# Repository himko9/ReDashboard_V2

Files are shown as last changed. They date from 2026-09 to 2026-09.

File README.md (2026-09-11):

# N-in-One Enhanced ReDashboard - Open-Source "EZ Dashboard" Based on the RP2040 MCU

English | [简体中文](./README.zh-CN.md)

<table>
  <tr>
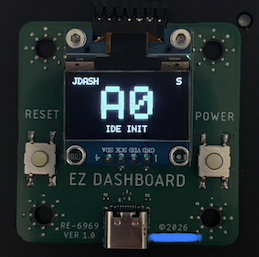
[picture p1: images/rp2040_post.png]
    <td></td>
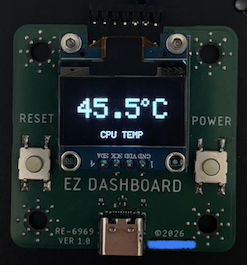
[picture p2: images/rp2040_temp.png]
    <td></td>
  </tr>
  <tr>
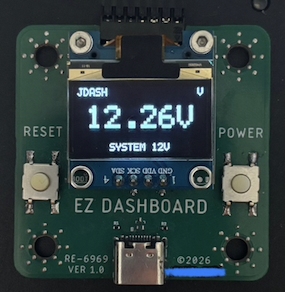
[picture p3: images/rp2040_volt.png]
    <td></td>
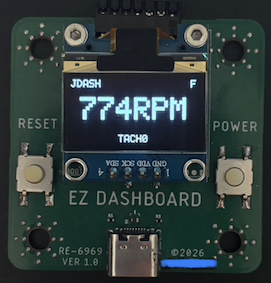
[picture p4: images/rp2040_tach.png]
    <td></td>
  </tr>
</table>

### Motherboard Support:

**Supports POST code monitoring through the following headers/interfaces:**

* JDASH1

* JDP1

* JBD1

* Any other UART header using 115200-8N1

**On MSI motherboards, connecting to "JDASH1" provides:**

* Display and logging of POST codes (Port80/81, 8-bit)

* Fan speed display

* System temperature display

* System voltage display

**On MSI motherboards, connecting to "JDP1" provides:**

* Display and logging of POST codes (Port80, 32-bit; Port81-83, 8-bit)

**On other motherboards, connecting to any header that outputs codes over UART 115200-8N1 provides:**

* Display and logging of POST codes (Port80, 8-bit)

**On all motherboards, additional connections to JBAT and JFP1 allow control of:**

* BIOS reset and system power on/off

### Firmware Features:

Code history:\
Supports caching P80 codes in the chip's internal memory.\
The onboard buttons can be used to scroll up and down through the recorded codes.

Code output:\
When connected via USB-C, the device operates as a USB CDC UART device.\
Supports decoded P80 code output.\
A future SDK will support voltage, temperature, and fan-speed logging.

Temperature / voltage / fan-speed sensors:\
Supports custom labels based on motherboard model.\
Supports Celsius / Fahrenheit temperature conversion.

OLED page control:\
Supports disabling unused pages, such as hiding the voltage page.\
Supports automatically returning to the home page after N seconds.\
Supports automatically waking the display when a significant change in temperature, voltage, or fan speed is detected.\
Supports automatically displaying updated POST codes.

OLED burn-in protection features:\
Pixel shifting.\
Automatic dimming.\
Automatic page-title hiding.\
Automatic display shutoff.

### Button Controls:

Short-press both side buttons -> Switch input source (JDASH/UART).\
Hold both side buttons for 3 seconds -> Switch button mode (page navigation mode / power-button mode).\
Hold both side buttons for 5 seconds -> Lock the JDASH/UART input and lock the buttons\
(buttons have no function while locked, Hold again to unlock).\
Hold both side buttons for 10 seconds -> Reset BIOS (NMOS connects JBAT1).

Press either side button 5 times consecutively -> Change page (switch display page).\
On the P80 page, hold either side button -> Scroll up/down through the P80 code history.

### BOM + Manufacturing Notes:
**If you want to reproduce the design directly, please note that the design was imported into JLCPCB/LCEDA from an external source.**\
**I cannot confirm whether Gerber files exported from this project can be used directly for PCB manufacturing.**\
**Please verify the schematic, PCB routing, and copper pours yourself.**\
**Using the Autodesk Eagle design files to generate gerber should be fine**

The reproduction cost is only about RMB 15:\
RMB 6 for a 0.96-inch, 4-pin I2C OLED module.\
RMB 5 for an RP2040 module, from which the RP2040, crystal oscillator, and SPI NOR flash are removed.\
RMB 4 for other capacitors, resistors, LDOs, and miscellaneous components.\
RMB 0 for a free 2-layer PCB (thanks to JLCPCB).

**Note:**\
Reproducing the RP2040 version of ReDashboard is not recommended here.\
A later version will use a PY32 as the main controller, reducing the chip cost significantly to about RMB 0.5, and requiring almost no external components.\
The firmware has already been written and successfully tested. It will be updated when I'm free.\
<br>

### Firmware and Firmware Source Code:
You can use the precompiled `firmware.uf2` file, but it is recommended that you modify the configuration and compile the firmware yourself.
<br>

### License:
Both the hardware and firmware of this project are licensed under the GPL (v3 or later).\
I provide no guarantees regarding the functionality or safety of this project.\
You are free to use, sell, and create products based on this project.

```
/*
 * This file is part of the "ReDashboard_V2" distribution.
 *
 * Copyright (C) 2026 @himko9 <me@himko.dev>
 * Github: https://github.com/himko9/ReDashboard_V2
 *
 * This program is free software: you can redistribute it and/or modify
 * it under the terms of the GNU General Public License as published by
 * the Free Software Foundation, either version 3 of the License, or
 * (at your option) any later version.
 *
 * This program is distributed in the hope that it will be useful,
 * but WITHOUT ANY WARRANTY; without even the implied warranty of
 * MERCHANTABILITY or FITNESS FOR A PARTICULAR PURPOSE.  See the
 * GNU General Public License for more details.
 *
 * You should have received a copy of the GNU General Public License
 * along with this program.  If not, see <https://www.gnu.org/licenses/>.
 */
 ```

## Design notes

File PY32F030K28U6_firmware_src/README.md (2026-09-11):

# EZ Dashboard PY32F030K28 Firmware

Standalone release source for the PY32F030K28U6 target. The required Puya
CMSIS/HAL files, startup code, and linker script are included.

## Requirements

- Arm GNU Toolchain with `arm-none-eabi-gcc` in `PATH`
- GNU Make for the Makefile build

## Build

On Windows:

```bat
build.bat
```

The Windows script only requires the Arm GNU Toolchain; GNU Make is not needed.

On Linux or macOS:

```sh
make
```

To use a toolchain outside `PATH`, set its executable prefix:

```sh
make PREFIX=/opt/arm-gnu-toolchain/bin/arm-none-eabi-
```

Build outputs are written to `build/`:

- `ez_dashboard_py32f030k28.elf`
- `ez_dashboard_py32f030k28.hex`
- `ez_dashboard_py32f030k28.bin`

The raw `.bin` image starts at flash address `0x08000000`. Use `make clean`
or `build.bat clean` to remove generated files.

Application and board settings are in the headers under `include/`.

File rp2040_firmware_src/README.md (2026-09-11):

# ReDashboard V2 - RP2040

This directory is a standalone Raspberry Pi Pico SDK project. It contains its
own firmware sources, configuration headers, POST-code table, PIO program,
Pico SDK import helper, and CMake project.

The user-editable configuration files are under `include/`:

- `app_config.h`: polling, display, button, sensor timing, and the percentage
  change required to wake the OLED.
- `display_config.h`: enabled pages, startup page, P81 decoding, and OLED
  power-saving/top-bar behavior.
- `sio_adc_config.h`: voltage/temperature channels, labels, and formulas.
- `sio_fan_config.h`: tachometer channels, labels, and formulas.
- `board_config.h`: RP2040 pins, buses, UARTs, buttons, and OLED rotation.

Configure and build from this directory with Pico SDK 2.2 or later:

```sh
cmake -S . -B build
cmake --build build --parallel
```

Targets:

- `redashboard`: normal P80-only flash build.
- `redashboard_p81_16bit`: P81/OUT16 flash build.
- `redashboard_ram`: normal P80-only RAM build.

By default, a valid sensor change greater than 10 percent wakes a dimmed or
powered-off OLED. The static source/role/lock top bar hides after 30 seconds
and reappears on activity. Configure these with
`SENSOR_WAKE_CHANGE_PERCENT` in `app_config.h` and
`DISPLAY_TOP_BAR_TIMEOUT_SECONDS` in `display_config.h`; zero disables the
corresponding feature.

UART mode keeps a lightweight P80-only JDASH probe active. A stable value is
used only as a baseline; a subsequent valid nonzero P80 transition switches
the display back to JDASH automatically. Configure its background interval
with `JDASH_DETECT_POLL_INTERVAL_MS` in `app_config.h`.

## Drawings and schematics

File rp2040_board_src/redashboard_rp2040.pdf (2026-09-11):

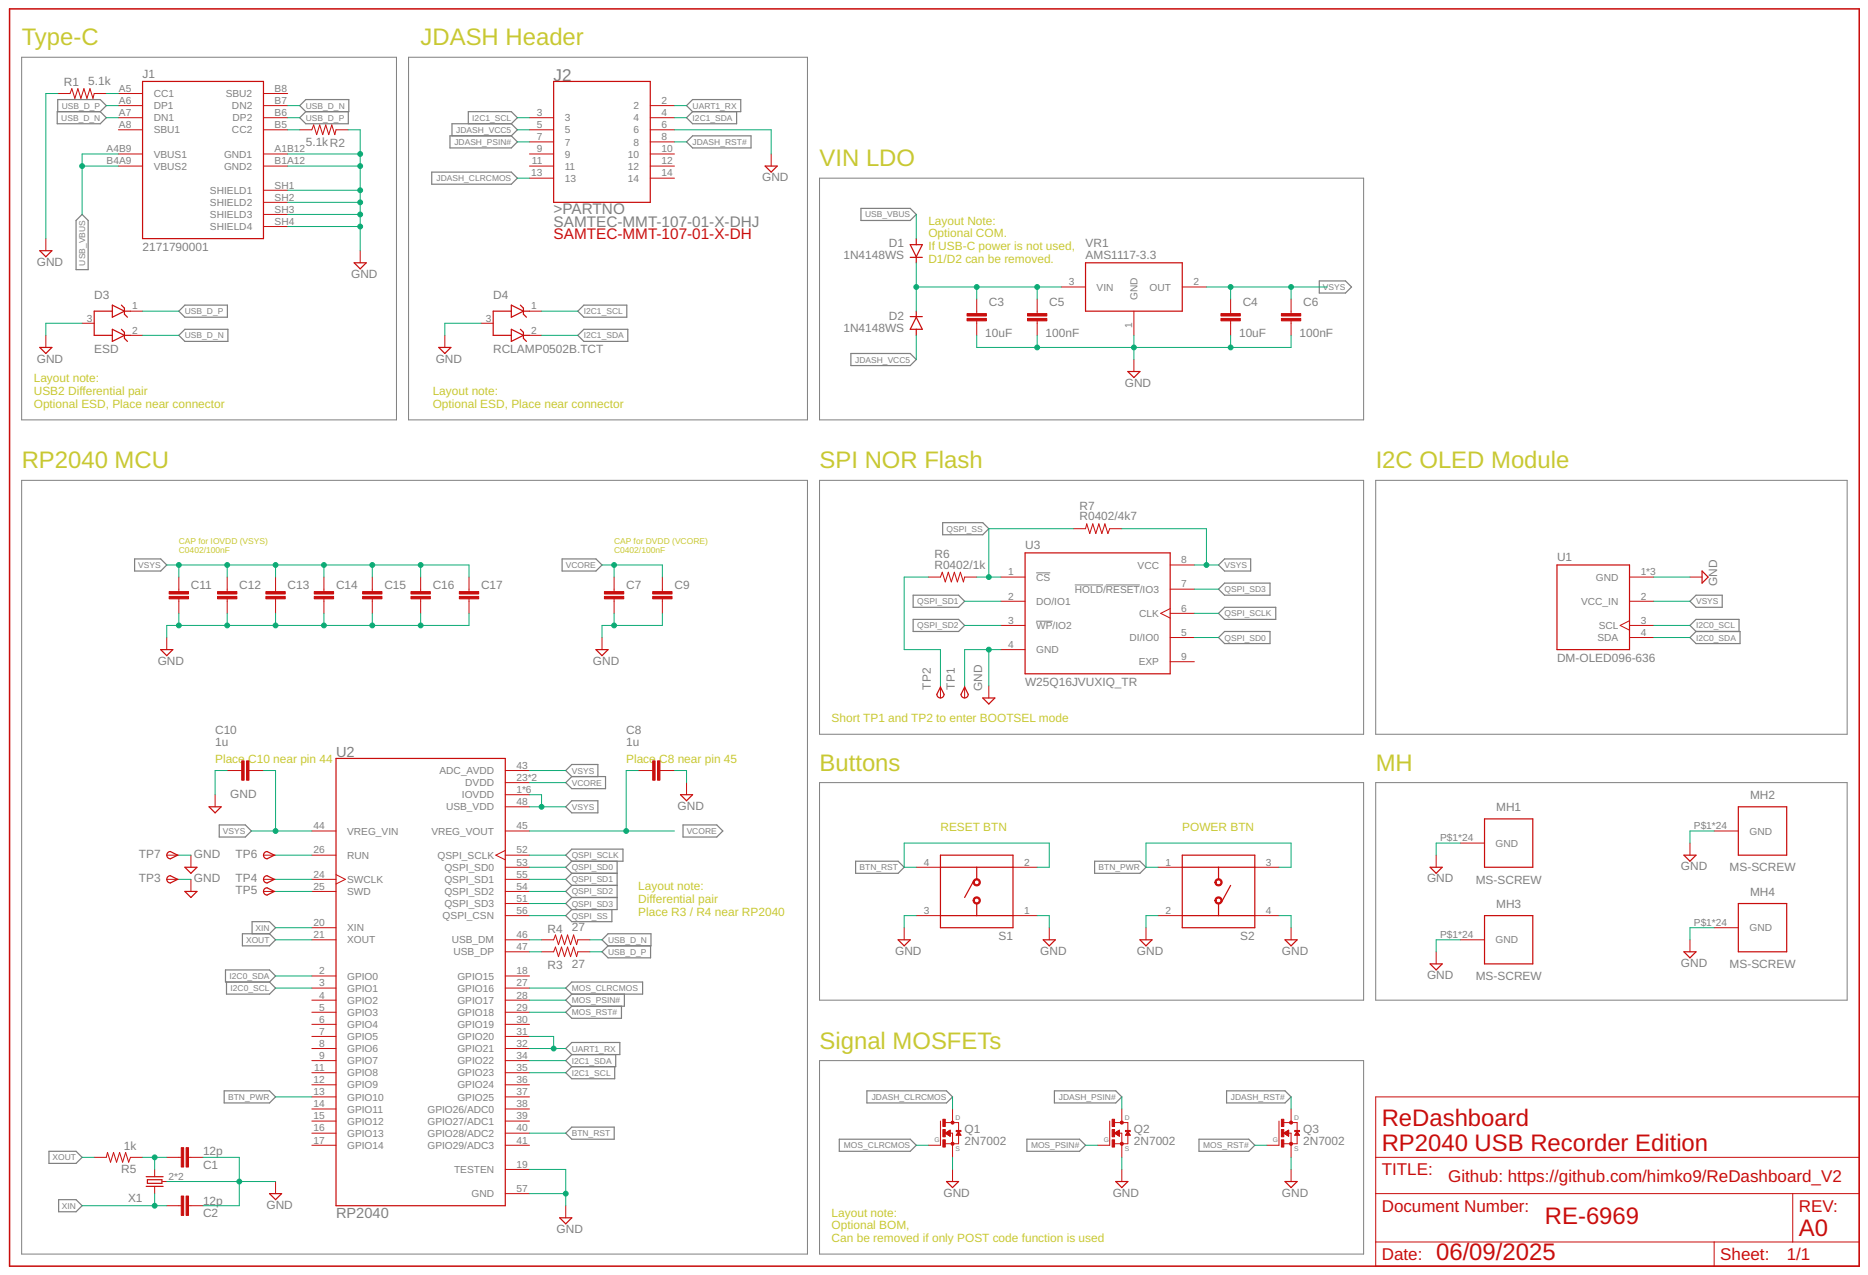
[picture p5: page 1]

Layout Note: Optional COM.

If USB-C power is not used, D1/D2 can be removed. RP2040 MCU
GND

Layout note: USB2 Differential pair Optional ESD, Place near connector

Layout note: Optional ESD, Place near connector

Short TP1 and TP2 to enter BOOTSEL mode
Buttons

Layout note: Differential pair Place R3 / R4 near RP2040

Github: https://github.com/himko9/ReDashboard_V2

Document Number: RE-6969 | REV: A0
06/09/2025 Date: | Sheet: 1/1

Layout note: Optional BOM, Can be removed if only POST code function is used

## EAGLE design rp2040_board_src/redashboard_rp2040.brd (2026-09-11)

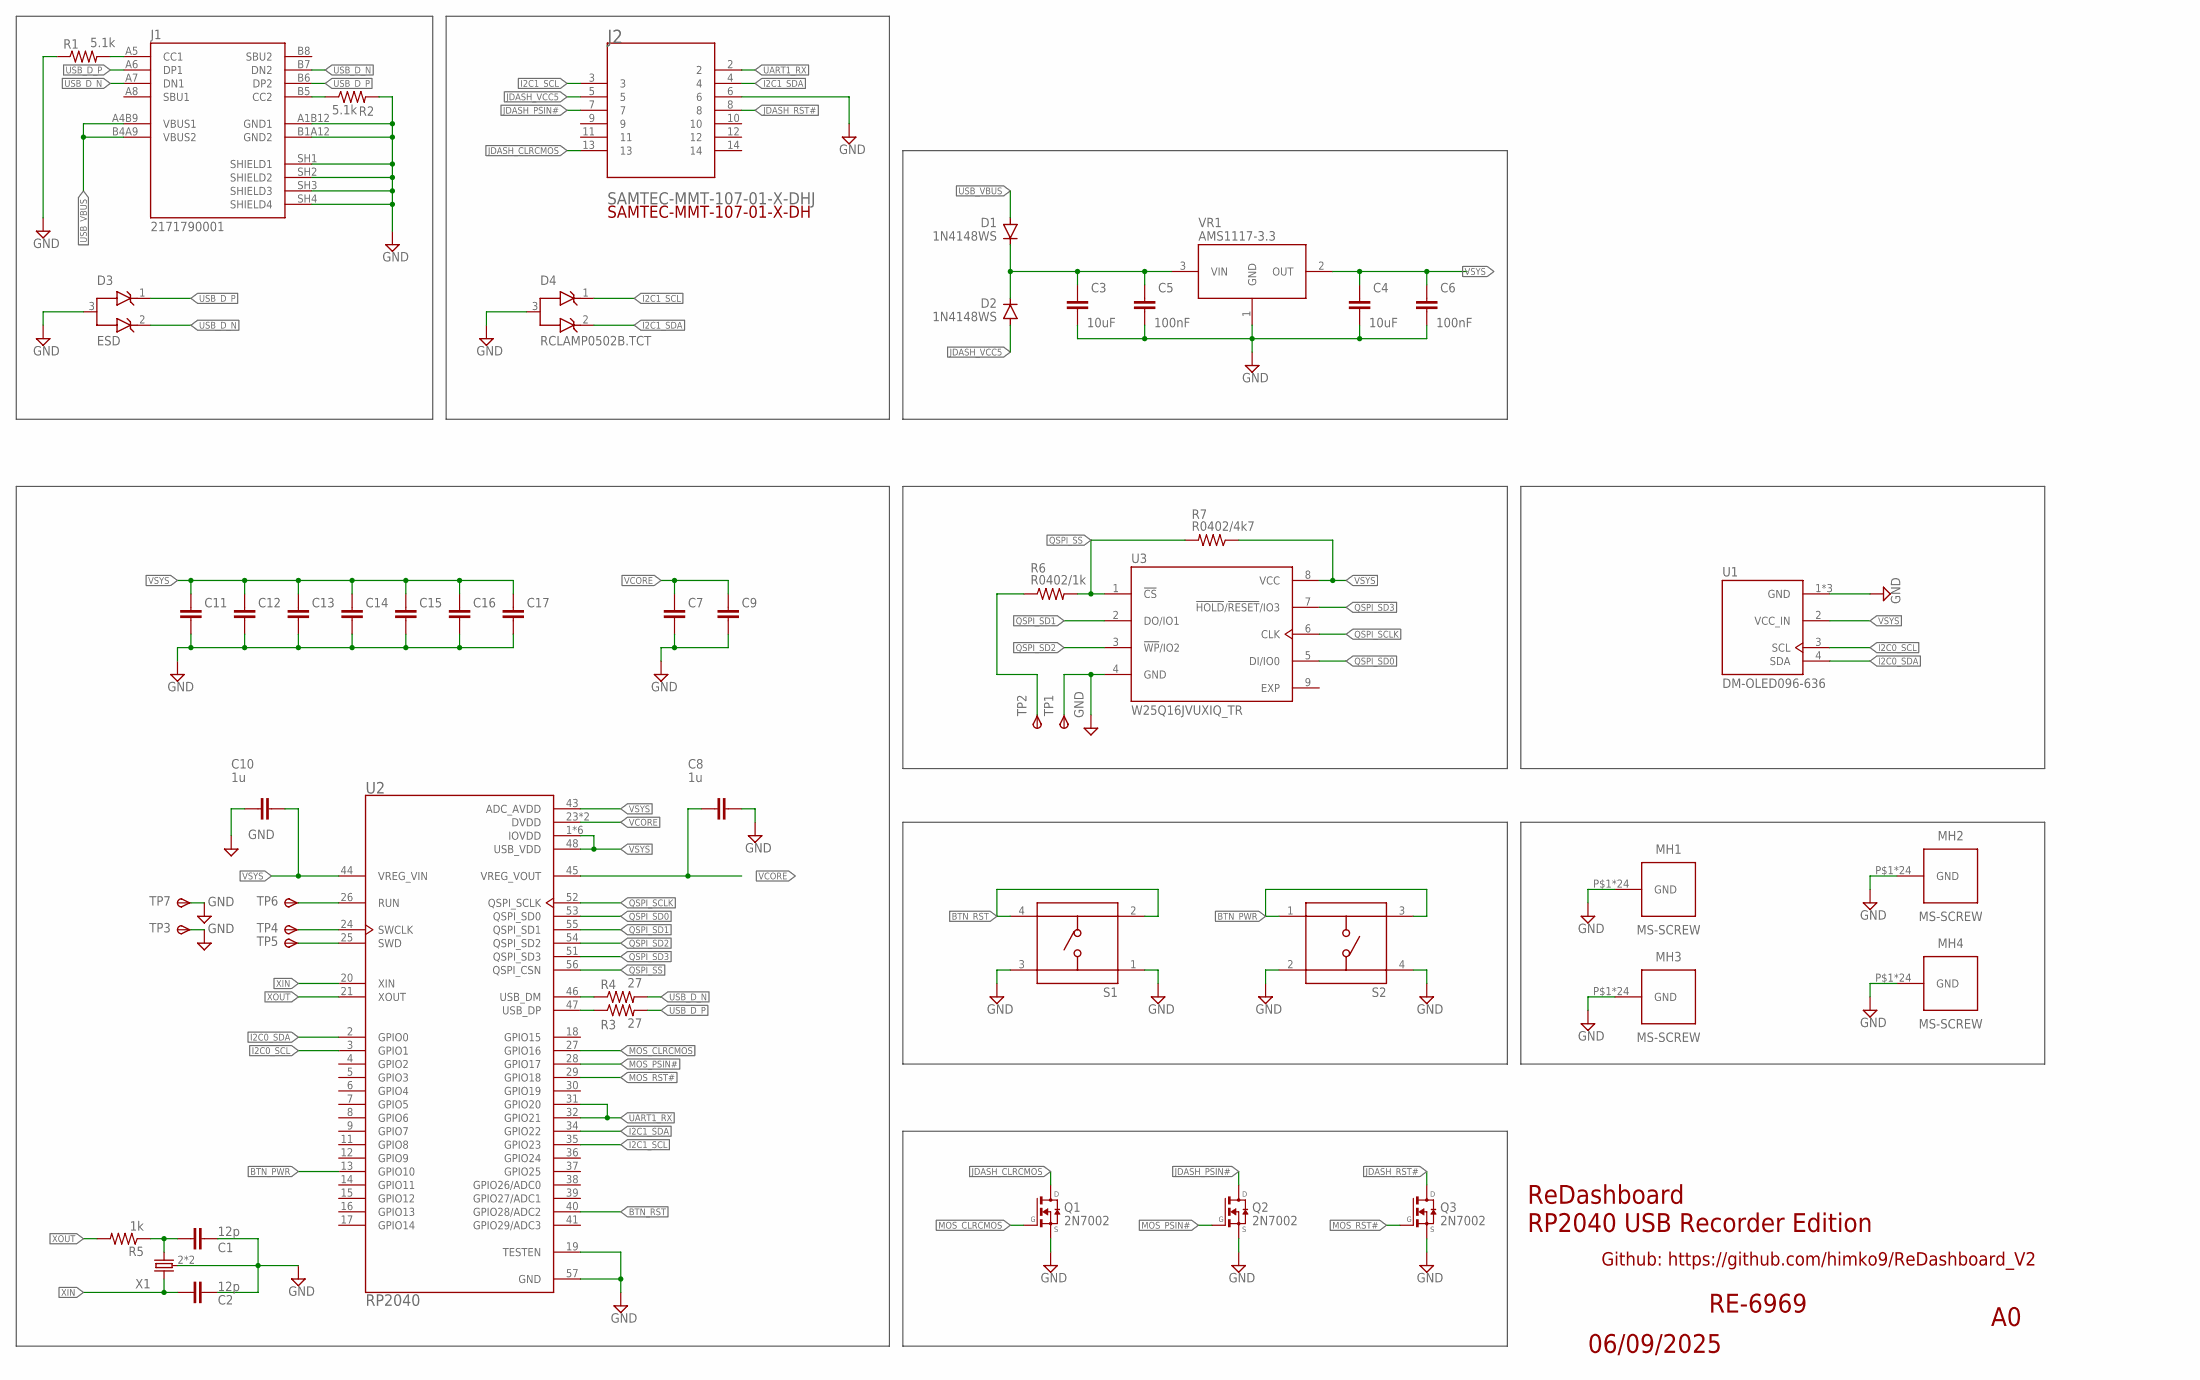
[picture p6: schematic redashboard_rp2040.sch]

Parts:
C1, C2: 12p; CAP_0402
C3, C4: 10uF; CAP_0603
C5, C6, C7, C11, C12, C13, C14, C15, C16, C17: 100nF; CAP_0402
C8, C10: 1u; CAP_0402
C9: CC0402CRNPO9BN1R0; CAP_0402
D1, D2: 1N4148WS; SOD-323
D3: ESD; TVS_RCLAMP0502B.TCT
D4: RCLAMP0502B.TCT; TVS_RCLAMP0502B.TCT
J1: 2171790001; MOLEX_2171790001
J2: SAMTEC-MMT-107-01-X-DHJ; SAMTEC-MMT-107-01-X-DH
MH1, MH2, MH3, MH4: MS-SCREW
Q1, Q2, Q3: 2N7002; TRANSISTOR-FET_SOT23
R1, R2: 5.1k; RES_0402
R3, R4: 27; RES_0402
R5: 1k; RES_0402
R6: R0402/1k; RES_0402
R7: R0402/4k7; RES_0402
S1, S2: TS04-66-50-BK-260-SMT; SW_TS04-66-50-BK-260-SMT
TP1, TP3, TP7: TPSTP10SQ; TP10SQ
TP2, TP4, TP5, TP6: TPSTP10R; TP10R
U1: DM-OLED096-636; MODULE_DM-OLED096-636
U2: RP2040; QFN40P700X700X90-57N
U3: W25Q16JVUXIQ_TR; IC_W25Q16JVUXIQ_TR
VR1: AMS1117-3.3; VREG_AZ1117CR2-5.0TRG1
X1: KX-6; 2.5X2.0_KX-6

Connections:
BTN_PWR: S2.1, S2.3, U2.13 (GPIO10)
BTN_RST: S1.2, S1.4, U2.40 (GPIO28/ADC2)
GND: C1.2, C2.2, C3.2, C4.2, C5.2, C6.2, C7.2, C8.2, C9.2, C10.1, C11.2, C12.2, C13.2, C14.2, C15.2, C16.2, C17.2, D3.3 (A), D4.3 (A), J1.A1B12 (GND1), J1.B1A12 (GND2), J1.SH1 (SHIELD1), J1.SH2 (SHIELD2), J1.SH3 (SHIELD3), J1.SH4 (SHIELD4), J2.6, MH1.P$1, MH1.P$2, MH1.P$3, MH1.P$4, MH1.P$5, MH1.P$6, MH1.P$7, MH1.P$8, MH1.P$9, MH1.P$10, MH1.P$11, MH1.P$12, MH1.P$13, MH1.P$14, MH1.P$15, MH1.P$16, MH1.P$17, MH1.P$18, MH1.P$19, MH1.P$20, MH1.P$21, MH1.P$22, MH1.P$23, MH1.P$24, MH2.P$1, MH2.P$2, MH2.P$3, MH2.P$4, MH2.P$5, MH2.P$6, MH2.P$7, MH2.P$8, MH2.P$9, MH2.P$10, MH2.P$11, MH2.P$12, MH2.P$13, MH2.P$14, MH2.P$15, MH2.P$16, MH2.P$17, MH2.P$18, MH2.P$19, MH2.P$20, MH2.P$21, MH2.P$22, MH2.P$23, MH2.P$24, MH3.P$1, MH3.P$2, MH3.P$3, MH3.P$4, MH3.P$5, MH3.P$6, MH3.P$7, MH3.P$8, MH3.P$9, MH3.P$10, MH3.P$11, MH3.P$12, MH3.P$13, MH3.P$14, MH3.P$15, MH3.P$16, MH3.P$17, MH3.P$18, MH3.P$19, MH3.P$20, MH3.P$21, MH3.P$22, MH3.P$23, MH3.P$24, MH4.P$1, MH4.P$2, MH4.P$3, MH4.P$4, MH4.P$5, MH4.P$6, MH4.P$7, MH4.P$8, MH4.P$9, MH4.P$10, MH4.P$11, MH4.P$12, MH4.P$13, MH4.P$14, MH4.P$15, MH4.P$16, MH4.P$17, MH4.P$18, MH4.P$19, MH4.P$20, MH4.P$21, MH4.P$22, MH4.P$23, MH4.P$24, Q1.2 (S), Q2.2 (S), Q3.2 (S), R1.1, R2.2, S1.1, S1.3, S2.2, S2.4, TP1.TP, TP3.TP, TP7.TP, U1.1 (GND), U1.S3 (GND), U1.S4 (GND), U2.19 (TESTEN), U2.57 (GND), U3.4 (GND), VR1.1 (GND), X1.2 (3), X1.4 (3)
I2C0_SCL: U1.3 (SCL), U2.3 (GPIO1)
I2C0_SDA: U1.4 (SDA), U2.2 (GPIO0)
I2C1_SCL: D4.1 (K1), J2.3, U2.35 (GPIO23)
I2C1_SDA: D4.2 (K2), J2.4, U2.34 (GPIO22)
JDASH_CLRCMOS: J2.13, Q1.3 (D)
JDASH_PSIN#: J2.7, Q2.3 (D)
JDASH_RST#: J2.8, Q3.3 (D)
JDASH_VCC5: D2.A, J2.5
MOS_CLRCMOS: Q1.1 (G), U2.27 (GPIO16)
MOS_PSIN#: Q2.1 (G), U2.28 (GPIO17)
MOS_RST#: Q3.1 (G), U2.29 (GPIO18)
unnamed: R6.1, TP2.TP
unnamed: C3.1, C5.1, D1.C, D2.C, VR1.3 (VIN)
unnamed: J1.B5 (CC2), R2.1
unnamed: C1.1, R5.1, X1.3 (2)
unnamed: J1.A5 (CC1), R1.2
unnamed: TP6.TP, U2.26 (RUN)
unnamed: TP4.TP, U2.24 (SWCLK)
unnamed: TP5.TP, U2.25 (SWD)
QSPI_SCLK: U2.52 (QSPI_SCLK), U3.6 (CLK)
QSPI_SD0: U2.53 (QSPI_SD0), U3.5 (DI/IO0)
QSPI_SD1: U2.55 (QSPI_SD1), U3.2 (DO/IO1)
QSPI_SD2: U2.54 (QSPI_SD2), U3.3 (!WP!/IO2)
QSPI_SD3: U2.51 (QSPI_SD3), U3.7 (!HOLD!/!RESET!/IO3)
QSPI_SS: R6.2, R7.2, U2.56 (QSPI_CSN), U3.1 (!CS)
UART1_RX: J2.2, U2.31 (GPIO20), U2.32 (GPIO21)
USB_D_N: D3.2 (K2), J1.A7 (DN1), J1.B7 (DN2), R4.2
USB_D_P: D3.1 (K1), J1.A6 (DP1), J1.B6 (DP2), R3.2
USB_D_R_N: R4.1, U2.46 (USB_DM)
USB_D_R_P: R3.1, U2.47 (USB_DP)
USB_VBUS: D1.A, J1.A4B9 (VBUS1), J1.B4A9 (VBUS2)
VCORE: C7.1, C8.1, C9.1, U2.23 (DVDD), U2.45 (VREG_VOUT), U2.50 (DVDD)
VSYS: C4.1, C6.1, C10.2, C11.1, C12.1, C13.1, C14.1, C15.1, C16.1, C17.1, R7.1, U1.2 (VCC_IN), U2.1 (IOVDD), U2.10 (IOVDD), U2.22 (IOVDD), U2.33 (IOVDD), U2.42 (IOVDD), U2.43 (ADC_AVDD), U2.44 (VREG_VIN), U2.48 (USB_VDD), U2.49 (IOVDD), U3.8 (VCC), VR1.2 (OUT)
XIN: C2.1, U2.20 (XIN), X1.1
XOUT: R5.2, U2.21 (XOUT)

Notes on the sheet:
RE-6969
ReDashboard RP2040 USB Recorder Edition
06/09/2025
Github: https://github.com/himko9/ReDashboard_V2

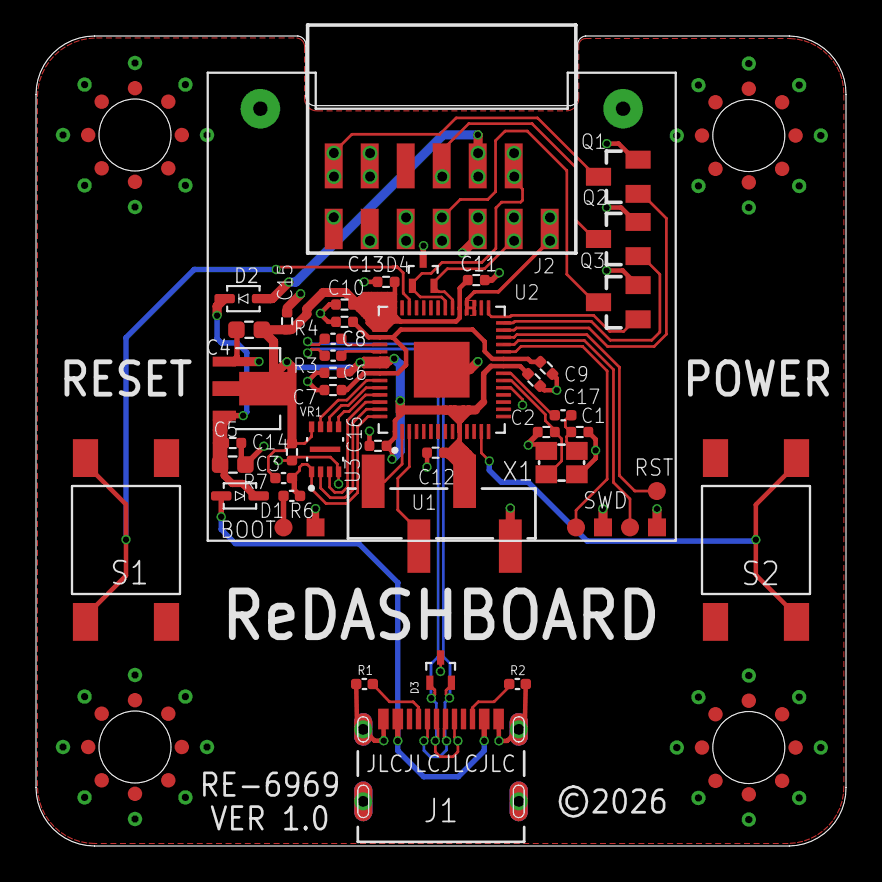
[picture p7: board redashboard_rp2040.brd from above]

Board: 2 copper layers, 45.0 x 45.0 mm, 51 parts (0 on the bottom side), 38 nets.

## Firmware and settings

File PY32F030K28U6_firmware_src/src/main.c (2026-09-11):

/*
 * This file is part of the "ReDashboard_V2" distribution.
 *
 * Copyright (C) 2026 @himko9 <me@himko.dev>
 * Github: https://github.com/himko9/ReDashboard_V2
 *
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
 * You should have received a copy of the GNU General Public License
 * along with this program.  If not, see <https://www.gnu.org/licenses/>.
 */

#include <stdbool.h>
#include <stdint.h>

#include "app_config.h"
#include "board.h"
#include "p80_post_codes.h"
#include "buttons.h"
#include "code_history.h"
#include "display_config.h"
#include "sio_adc_config.h"
#include "sio_fan_config.h"
#include "sio_i2c_hw.h"
#include "ssd1315.h"
#include "uart_fast_rx.h"
#include "uart_parser.h"
#include "uart_rx.h"

typedef enum {
    SOURCE_I2C = 0,
    SOURCE_UART,
} DataSource;

typedef enum {
    UART_INPUT_NONE = 0,
    UART_INPUT_115200,
    UART_INPUT_1500000,
} UartInput;

typedef enum {
    BUTTON_ROLE_BROWSE = 0,
    BUTTON_ROLE_GPIO,
} ButtonRole;

typedef enum {
    DISPLAY_PAGE_POST = 0,
    DISPLAY_PAGE_VOLTAGE,
    DISPLAY_PAGE_TEMPERATURE,
    DISPLAY_PAGE_FAN,
} DisplayPage;

typedef enum {
    SENSOR_READ_NONE = 0,
    SENSOR_READ_BYTE,
    SENSOR_READ_WORD_HIGH,
    SENSOR_READ_WORD_LOW,
} SensorReadPhase;

typedef int32_t (*SensorCalculate)(uint16_t raw);

typedef struct {
    uint8_t enabled;
    uint8_t type;
    uint8_t index;
    const char *label;
    SensorCalculate calculate;
} SensorDefinition;

#define DEFINE_SENSOR_CALCULATOR(id, enabled, type, index, label, calculate) \
    static int32_t sensor_calculate_##id(uint16_t raw)                      \
    {                                                                       \
        return (int32_t)(calculate(raw));                                    \
    }
SENSOR_TABLE(DEFINE_SENSOR_CALCULATOR)
SIO_TACH_TABLE(DEFINE_SENSOR_CALCULATOR)
#undef DEFINE_SENSOR_CALCULATOR

#define DEFINE_SENSOR_ENTRY(id, enabled, type, index, label, calculate) \
    {(enabled), (type), (index), (label), sensor_calculate_##id},
static const SensorDefinition sensors[] = {
    SENSOR_TABLE(DEFINE_SENSOR_ENTRY)
    SIO_TACH_TABLE(DEFINE_SENSOR_ENTRY)
};
#undef DEFINE_SENSOR_ENTRY

#define VALIDATE_SENSOR_ENTRY(id, enabled, type, index, label, calculate)    \
    _Static_assert(((enabled) == 0U) || ((enabled) == 1U),                  \
                   #id " ENABLED must be 0 or 1");                          \
    _Static_assert(((type) == SENSOR_TYPE_VIN) ||                           \
                       ((type) == SENSOR_TYPE_THR) ||                       \
                       ((type) == SENSOR_TYPE_TACH),                        \
                   #id " TYPE must be VIN, THR, or TACH");                 \
    _Static_assert((index) < 0xFFU, #id " INDEX must be below 0xFF");
SENSOR_TABLE(VALIDATE_SENSOR_ENTRY)
SIO_TACH_TABLE(VALIDATE_SENSOR_ENTRY)
#undef VALIDATE_SENSOR_ENTRY

#define SENSOR_COUNT ((uint8_t)(sizeof(sensors) / sizeof(sensors[0])))
_Static_assert((sizeof(sensors) / sizeof(sensors[0])) <= 32U,
               "SENSOR_TABLE supports at most 32 entries");

typedef struct {
    CodeHistory history;
    ButtonState previous_button;
    ButtonState next_button;

    DataSource source;
    UartInput uart_input;
    uint32_t fast_uart_record_count;
    uint32_t fast_uart_error_count;
    ButtonRole button_role;
    bool mode_locked;

    bool browse_active;
    uint32_t browse_cursor;
    uint32_t browse_enter_total;
    uint32_t browse_deadline_ms;

    DisplayPage display_page;
    uint8_t up_click_count;
    uint8_t down_click_count;
    uint32_t page_click_deadline_ms;
    uint8_t sensor_index;
    uint32_t sensor_page_deadline_ms;
    bool sensor_refresh_pending;
    SensorReadPhase sensor_read_phase;
    bool sensor_read_inflight;
    uint8_t sensor_request_slot;
    uint8_t sensor_word_high;
    uint32_t sensor_retry_ms;
    bool post_override_active;
    uint32_t post_override_deadline_ms;
    int32_t sensor_values[SENSOR_COUNT];
    uint32_t sensor_valid_mask;

    PostCode last_enqueued_code;
    bool last_enqueued_valid;
    PostCode current_code;
    uint8_t port81_code;
    uint8_t port81_zero_polls;
    bool port81_visible;
    bool postcode_error_active;
    bool sio_error_candidate;
    uint32_t sio_error_since_ms;

    bool display_panel_on;
    bool display_dimmed;
    bool display_top_bar_visible;
    bool display_frame_flushing;
    uint32_t display_last_activity_ms;
    uint32_t next_display_ms;
    uint32_t next_shift_ms;
    uint32_t next_display_retry_ms;
    uint32_t next_poll_ms;

    bool both_pressed_latch;
    bool combo_short_armed;
    bool combo_role_fired;
    bool combo_lock_fired;
    bool combo_clear_fired;
    uint32_t combo_start_ms;

    bool previous_output_fired;
    bool next_output_fired;
    bool singles_suppressed_until_release;
    bool power_output_on;
    bool reset_output_on;
    bool clear_output_on;
} Application;

static Application app;

static void leave_browse_mode(uint32_t now_ms);
static void display_redraw(bool mark_activity, uint32_t now_ms);

static bool time_reached(uint32_t now_ms, uint32_t deadline_ms)
{
    return (int32_t)(now_ms - deadline_ms) >= 0;
}

static DisplayContext display_context(bool show_scrollbar)
{
    DisplayContext context;

    context.source = app.source == SOURCE_UART ? DISPLAY_SOURCE_UART : DISPLAY_SOURCE_I2C;
    context.role_tag = app.button_role == BUTTON_ROLE_BROWSE ? 'S' : 'G';
    context.show_top_bar = app.display_top_bar_visible;
    context.locked = app.mode_locked;
    context.show_scrollbar = show_scrollbar;
    context.meaning = NULL;
    context.oldest = app.history.count > 0U ? code_history_oldest(&app.history) : 0U;
    context.newest = app.history.count > 0U ? code_history_newest(&app.history) : 0U;
    context.cursor = app.browse_cursor;
    return context;
}

static void display_wake(uint32_t now_ms)
{
    bool restore_full_contrast;

    if (!ssd1315_is_online()) {
        return;
    }
    app.display_top_bar_visible = true;
    restore_full_contrast = !app.display_panel_on || app.display_dimmed;
    if (!app.display_panel_on) {
        if (!ssd1315_set_power(true)) {
            return;
        }
        app.display_panel_on = true;
    }
    if (restore_full_contrast) {
        if (!ssd1315_set_contrast(DISPLAY_CONTRAST_FULL)) {
            return;
        }
        app.display_dimmed = false;
    }
    app.display_last_activity_ms = now_ms;
}

static void display_code(PostCode code,
                         bool show_scrollbar,
                         bool mark_activity,
                         uint32_t now_ms)
{
    DisplayContext context;

    app.current_code = code;
    if (!ssd1315_is_online()) {
        return;
    }
    if (mark_activity) {
        app.display_top_bar_visible = true;
    }
    if (mark_activity && (!app.display_panel_on || app.display_dimmed)) {
        display_wake(now_ms);
    }
    if (!app.display_panel_on) {
        return;
    }
    context = display_context(show_scrollbar);
    if (app.postcode_error_active && (code.value == 0U) &&
        (code.width_bytes == 1U)) {
        context.meaning = "SIO COMM ERROR";
    } else if (code.width_bytes == 1U) {
        context.meaning = p80_post_code_label((uint8_t)code.value);
    } else {
        context.meaning = NULL;
    }
    if ((app.source == SOURCE_I2C) && app.port81_visible &&
        !show_scrollbar && !app.postcode_error_active &&
        (code.width_bytes == 1U)) {
        ssd1315_render_post_pair((uint8_t)code.value,
                                 app.port81_code,
                                 &context);
    } else {
        ssd1315_render_code(code.value, code.width_bytes, &context);
    }
    app.display_frame_flushing = ssd1315_is_busy();
    if (mark_activity) {
        app.display_last_activity_ms = now_ms;
    }
}

static void format_voltage(int32_t calculated_millivolts, char value[9])
{
    uint32_t millivolts = calculated_millivolts > 0
                              ? (uint32_t)calculated_millivolts
                              : 0U;
    uint32_t rounded_units;
    uint32_t whole;
#if SENSOR_VOLTAGE_DECIMAL_DIGITS > 0U
    uint32_t fraction;
#endif
    uint8_t offset = 0U;

#if SENSOR_VOLTAGE_DECIMAL_DIGITS == 0U
    rounded_units = ((uint32_t)millivolts + 500U) / 1000U;
    whole = rounded_units;
#elif SENSOR_VOLTAGE_DECIMAL_DIGITS == 1U
    rounded_units = ((uint32_t)millivolts + 50U) / 100U;
    whole = rounded_units / 10U;
    fraction = rounded_units % 10U;
#elif SENSOR_VOLTAGE_DECIMAL_DIGITS == 2U
    rounded_units = ((uint32_t)millivolts + 5U) / 10U;
    whole = rounded_units / 100U;
    fraction = rounded_units % 100U;
#else
    rounded_units = millivolts;
    whole = rounded_units / 1000U;
    fraction = rounded_units % 1000U;
#endif

    if (whole >= 100U) {
        value[offset++] = (char)('0' + (whole / 100U) % 10U);
    }
    if (whole >= 10U) {
        value[offset++] = (char)('0' + (whole / 10U) % 10U);
    }
    value[offset++] = (char)('0' + whole % 10U);
#if SENSOR_VOLTAGE_DECIMAL_DIGITS > 0U
    value[offset++] = '.';
#if SENSOR_VOLTAGE_DECIMAL_DIGITS == 3U
    value[offset++] = (char)('0' + fraction / 100U);
#endif
#if SENSOR_VOLTAGE_DECIMAL_DIGITS >= 2U
    value[offset++] = (char)('0' + (fraction / 10U) % 10U);
#endif
    value[offset++] = (char)('0' + fraction % 10U);
#endif
    value[offset++] = 'V';
    value[offset] = '\0';
}

static void format_temperature(int32_t tenths_celsius, char value[9])
{
    int32_t tenths;
    uint32_t magnitude;
    uint32_t whole;
    uint32_t fraction;
    uint8_t offset = 0U;

#if SENSOR_TEMP_UNIT == 'F'
    {
        int32_t fahrenheit_delta = tenths_celsius * 9;

        tenths = (fahrenheit_delta >= 0
                      ? (fahrenheit_delta + 2) / 5
                      : (fahrenheit_delta - 2) / 5) +
                 320;
    }
#else
    tenths = tenths_celsius;
#endif
    magnitude = tenths < 0 ? (uint32_t)(-tenths) : (uint32_t)tenths;
    whole = magnitude / 10U;
    fraction = magnitude % 10U;

    if (tenths < 0) {
        value[offset++] = '-';
    }
    if (whole >= 100U) {
        value[offset++] = (char)('0' + (whole / 100U) % 10U);
    }
    if (whole >= 10U) {
        value[offset++] = (char)('0' + (whole / 10U) % 10U);
    }
    value[offset++] = (char)('0' + whole % 10U);
    value[offset++] = '.';
    value[offset++] = (char)('0' + fraction);
    value[offset++] = '^';
    value[offset++] = SENSOR_TEMP_UNIT;
    value[offset] = '\0';
}

static void format_rpm(int32_t calculated_rpm, char value[9])
{
    uint32_t rpm = calculated_rpm > 0 ? (uint32_t)calculated_rpm : 0U;
    uint32_t divisor = 10000U;
    uint8_t offset = 0U;
    bool started = false;

    if (rpm > UINT16_MAX) {
        rpm = UINT16_MAX;
    }
    while (divisor != 0U) {
        uint8_t digit = (uint8_t)((rpm / divisor) % 10U);

        if ((digit != 0U) || started || (divisor == 1U)) {
            value[offset++] = (char)('0' + digit);
            started = true;
        }
        divisor /= 10U;
    }
    value[offset++] = 'R';
    value[offset++] = 'P';
    value[offset++] = 'M';
    value[offset] = '\0';
}

static void display_sensor_page(bool mark_activity, uint32_t now_ms)
{
    DisplayContext context;
    const SensorDefinition *sensor;
    char value[9] = "WAIT";

    if ((app.display_page == DISPLAY_PAGE_POST) || !ssd1315_is_online()) {
        return;
    }
    if (mark_activity) {
        app.display_top_bar_visible = true;
    }
    if (mark_activity && (!app.display_panel_on || app.display_dimmed)) {
        display_wake(now_ms);
    }
    if (!app.display_panel_on) {
        return;
    }

    context = display_context(false);
    if (app.postcode_error_active) {
        context.meaning = "SIO COMM ERROR";
        context.role_tag = '!';
        ssd1315_render_value("ERROR", &context);
        app.display_frame_flushing = ssd1315_is_busy();
        if (mark_activity) {
            app.display_last_activity_ms = now_ms;
        }
        return;
    }

    sensor = &sensors[app.sensor_index];
    context.meaning = sensor->label;
    if (sensor->type == SENSOR_TYPE_VIN) {
        context.role_tag = 'V';
        if ((app.sensor_valid_mask &
             (UINT32_C(1) << app.sensor_index)) != 0U) {
            format_voltage(app.sensor_values[app.sensor_index], value);
        }
    } else if (sensor->type == SENSOR_TYPE_THR) {
        context.role_tag = 'T';
        if ((app.sensor_valid_mask &
             (UINT32_C(1) << app.sensor_index)) != 0U) {
            format_temperature(app.sensor_values[app.sensor_index], value);
        }
    } else {
        context.role_tag = 'F';
        if ((app.sensor_valid_mask &
             (UINT32_C(1) << app.sensor_index)) != 0U) {
            format_rpm(app.sensor_values[app.sensor_index], value);
        }
    }
    ssd1315_render_value(value, &context);
    app.display_frame_flushing = ssd1315_is_busy();
    if (mark_activity) {
        app.display_last_activity_ms = now_ms;
    }
}

static void reset_page_click_sequence(void)
{
    app.up_click_count = 0U;
    app.down_click_count = 0U;
    app.page_click_deadline_ms = 0U;
}

static bool sensor_matches_page(uint8_t sensor_index, DisplayPage page)
{
    uint8_t required_type;

    if ((sensor_index >= SENSOR_COUNT) ||
        ((page != DISPLAY_PAGE_VOLTAGE) &&
         (page != DISPLAY_PAGE_TEMPERATURE) &&
         (page != DISPLAY_PAGE_FAN))) {
        return false;
    }
    if (page == DISPLAY_PAGE_VOLTAGE) {
#if DISPLAY_VOLTAGE_PAGE_ENABLED == 0U
        return false;
#endif
        required_type = SENSOR_TYPE_VIN;
    } else if (page == DISPLAY_PAGE_TEMPERATURE) {
#if DISPLAY_TEMPERATURE_PAGE_ENABLED == 0U
        return false;
#endif
        required_type = SENSOR_TYPE_THR;
    } else {
#if DISPLAY_FAN_PAGE_ENABLED == 0U
        return false;
#endif
        required_type = SENSOR_TYPE_TACH;
    }
    return (sensors[sensor_index].enabled != 0U) &&
           (sensors[sensor_index].type == required_type);
}

static bool first_sensor_for_page(DisplayPage page, uint8_t *sensor_index)
{
    uint8_t index;

    for (index = 0U; index < SENSOR_COUNT; ++index) {
        if (sensor_matches_page(index, page)) {
            *sensor_index = index;
            return true;
        }
    }
    return false;
}

static uint8_t next_sensor_for_page(DisplayPage page, uint8_t current)
{
    uint8_t offset;

    for (offset = 1U; offset <= SENSOR_COUNT; ++offset) {
        uint8_t candidate = (uint8_t)((current + offset) % SENSOR_COUNT);

        if (sensor_matches_page(candidate, page)) {
            return candidate;
        }
    }
    return current;
}

static void enter_sensor_page(DisplayPage page,
                              uint32_t now_ms,
                              bool mark_activity)
{
    uint8_t first_sensor;

    if ((app.source != SOURCE_I2C) || (app.button_role != BUTTON_ROLE_BROWSE) ||
        ((page != DISPLAY_PAGE_VOLTAGE) &&
         (page != DISPLAY_PAGE_TEMPERATURE) &&
         (page != DISPLAY_PAGE_FAN)) ||
        !first_sensor_for_page(page, &first_sensor)) {
        return;
    }

    if (app.browse_active) {
        leave_browse_mode(now_ms);
    }
    app.display_page = page;
    app.sensor_index = first_sensor;
    app.sensor_page_deadline_ms = now_ms + SENSOR_PAGE_INTERVAL_MS;
    app.sensor_refresh_pending = true;
    app.post_override_active = false;
    reset_page_click_sequence();
    display_sensor_page(mark_activity, now_ms);
}

static void exit_sensor_page(uint32_t now_ms)
{
    if (app.display_page == DISPLAY_PAGE_POST) {
        return;
    }

    app.display_page = DISPLAY_PAGE_POST;
    app.sensor_refresh_pending = false;
    app.post_override_active = false;
    if (!app.sensor_read_inflight) {
        app.sensor_read_phase = SENSOR_READ_NONE;
    }
    reset_page_click_sequence();
    display_redraw(true, now_ms);
}

static void display_redraw(bool mark_activity, uint32_t now_ms)
{
    PostCode code;

    if (app.display_page != DISPLAY_PAGE_POST) {
        display_sensor_page(mark_activity, now_ms);
    } else if (app.browse_active && (app.history.count > 0U) &&
        code_history_get(&app.history, app.browse_cursor, &code)) {
        display_code(code, true, mark_activity, now_ms);
    } else {
        display_code(app.current_code, false, mark_activity, now_ms);
    }
}

static void reset_code_pipeline(uint32_t now_ms)
{
    code_history_init(&app.history);
    app.last_enqueued_code.value = 0U;
    app.last_enqueued_code.width_bytes = 1U;
    app.last_enqueued_valid = false;
    app.browse_active = false;
    app.display_page = DISPLAY_PAGE_POST;
    app.sensor_refresh_pending = false;
    app.post_override_active = false;
    if (!app.sensor_read_inflight) {
        app.sensor_read_phase = SENSOR_READ_NONE;
    }
    reset_page_click_sequence();
    app.port81_code = 0U;
    app.port81_zero_polls = 0U;
    app.port81_visible = false;
    app.postcode_error_active = false;
    app.sio_error_candidate = false;
    app.next_display_ms = now_ms + DISPLAY_CODE_HOLD_MS;
    app.current_code.value = 0U;
    app.current_code.width_bytes = 1U;
    display_code(app.current_code, false, true, now_ms);
}

static void start_post_override(uint32_t now_ms)
{
    if (app.display_page != DISPLAY_PAGE_POST) {
        exit_sensor_page(now_ms);
    } else {
        bool panel_was_off = !app.display_panel_on;

        display_wake(now_ms);
        if (panel_was_off && app.display_panel_on) {
            display_redraw(false, now_ms);
        }
    }

    if ((app.source == SOURCE_I2C) &&
        (DEFAULT_BOOT_SCREEN != BOOT_SCREEN_POST) &&
        (DISPLAY_POST_RETURN_DELAY_MS != 0U)) {
        app.post_override_active = true;
        app.post_override_deadline_ms =
            now_ms + DISPLAY_POST_RETURN_DELAY_MS;
    } else {
        app.post_override_active = false;
    }
}

static void switch_source(DataSource source, uint32_t now_ms)
{
    if (app.source == source) {
        return;
    }
    app.source = source;
    app.next_poll_ms = now_ms;
    reset_code_pipeline(now_ms);
}

static void ingest_code(uint32_t value,
                        uint8_t width_bytes,
                        bool accept_zero,
                        uint32_t now_ms)
{
    PostCode code;

    if ((width_bytes != 1U) && (width_bytes != 2U) &&
        (width_bytes != 4U)) {
        return;
    }
    if (width_bytes == 1U) {
        value &= 0xFFU;
    } else if (width_bytes == 2U) {
        value &= 0xFFFFU;
    }
    if (!accept_zero && (value == 0U)) {
        return;
    }
    code.value = value;
    code.width_bytes = width_bytes;
    if (app.last_enqueued_valid &&
        (app.last_enqueued_code.value == code.value) &&
        (app.last_enqueued_code.width_bytes == code.width_bytes)) {
        return;
    }
    code_history_push(&app.history, code);
    app.last_enqueued_code = code;
    app.last_enqueued_valid = true;
    start_post_override(now_ms);
}

static void ingest_port81(uint8_t code, uint32_t now_ms)
{
#if POSTCODE_P81_DECODE_ENABLED == 0U
    (void)code;
    (void)now_ms;
    return;
#else
    bool redraw = false;

    if (code != 0U) {
        redraw = !app.port81_visible || (app.port81_code != code);
        app.port81_code = code;
        app.port81_zero_polls = 0U;
        app.port81_visible = true;
    } else if (app.port81_visible) {
        if (app.port81_zero_polls < PORT81_ZERO_HIDE_POLLS) {
            ++app.port81_zero_polls;
        }
        if (app.port81_zero_polls >= PORT81_ZERO_HIDE_POLLS) {
            app.port81_zero_polls = 0U;
            app.port81_visible = false;
            redraw = true;
        }
    }

    if (redraw) {
        start_post_override(now_ms);
        if (!app.browse_active &&
            (app.display_page == DISPLAY_PAGE_POST)) {
            display_redraw(true, now_ms);
        }
    }
#endif
}

static void service_uart(uint32_t now_ms)
{
    uint8_t byte;
    uint64_t raw;
    UartFastRecord record;
    uint32_t fast_record_count;
    uint32_t fast_error_count;

    fast_record_count = uart_fast_rx_record_count();
    if (fast_record_count != app.fast_uart_record_count) {
        app.fast_uart_record_count = fast_record_count;
    }
    fast_error_count = uart_fast_rx_error_count();
    if (fast_error_count != app.fast_uart_error_count) {
        app.fast_uart_error_count = fast_error_count;
    }

    /* Service the custom variable-width stream first. Its timer/DMA receiver
       returns one reconstructed port/width/payload word at a time. */
    while (uart_fast_rx_pop(&raw)) {
        if (!uart_fast_record_decode(raw, &record)) {
            continue;
        }
        if (app.uart_input != UART_INPUT_1500000) {
            app.uart_input = UART_INPUT_1500000;
            if (app.source == SOURCE_UART) {
                reset_code_pipeline(now_ms);
            }
        }
        if (app.source != SOURCE_UART) {
            switch_source(SOURCE_UART, now_ms);
        }
        /* UART mode remains Port-80-only, but Port 80 writes retain their
           wire width. OUT16 is displayed in ascending port order: P80, P81. */
        if (record.port == 0x0080U) {
            uint8_t width_bytes = (uint8_t)(1U << record.width);
            uint32_t display_value = record.payload;

            if (width_bytes == 2U) {
                uint8_t port80 = (uint8_t)record.payload;
#if POSTCODE_P81_DECODE_ENABLED != 0U
                uint8_t port81 = (uint8_t)(record.payload >> 8U);

                if ((port81 == 0x00U) || (port81 == 0xFFU)) {
                    display_value = port80;
                    width_bytes = 1U;
                } else {
                    display_value = ((uint32_t)port80 << 8U) | port81;
                }
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
int main(void)
{
    application_init();

    for (;;) {
        uint32_t now_ms = HAL_GetTick();

        service_uart(now_ms);
        service_sio_i2c(now_ms);
        service_buttons(now_ms);
        service_display(now_ms);
    }
}

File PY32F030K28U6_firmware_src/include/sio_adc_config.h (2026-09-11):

/*
 * This file is part of the "ReDashboard_V2" distribution.
 *
 * Copyright (C) 2026 @himko9 <me@himko.dev>
 * Github: https://github.com/himko9/ReDashboard_V2
 *
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
 * You should have received a copy of the GNU General Public License
 * along with this program.  If not, see <https://www.gnu.org/licenses/>.
 */

#ifndef EZDASH_SIO_ADC_CONFIG_H
#define EZDASH_SIO_ADC_CONFIG_H

#include <stdint.h>

/* Voltage digits after the decimal point: supported range is 0 through 3. */
#define SENSOR_VOLTAGE_DECIMAL_DIGITS 2U

#if SENSOR_VOLTAGE_DECIMAL_DIGITS > 3U
#error "SENSOR_VOLTAGE_DECIMAL_DIGITS must be between 0 and 3"
#endif

/* Temperature display unit: use 'C' for degrees Celsius or 'F' for Fahrenheit. */
#define SENSOR_TEMP_UNIT 'C'

#if (SENSOR_TEMP_UNIT != 'C') && (SENSOR_TEMP_UNIT != 'F')
#error "SENSOR_TEMP_UNIT must be 'C' or 'F'"
#endif

/*
 * Per-sensor configuration.
 *
 * ENABLED:   1 reads and displays the sensor; 0 omits it completely.
 * TYPE:      VIN reads one byte and appears on the voltage page.
 *            THR reads index/index+1 and appears on the temperature page.
 *            TACH reads index/index+1 and appears on the fan page.
 * INDEX:     first Page-01 data register for this monitor slot.
 * LABEL:     OLED text, at most 21 characters.
 * CALCULATE: VIN formulas return millivolts; THR formulas return 0.1 C;
 *            TACH formulas return RPM.
 *
 * A muxed analog pin such as THR6/VIN6 is one physical ADC. Change its use by
 * editing TYPE, INDEX, LABEL, and CALCULATE for that SIO_ADCn entry.
 */
#define SENSOR_TYPE_VIN 0U
#define SENSOR_TYPE_THR 1U
#define SENSOR_TYPE_TACH 2U

/* Default Nuvoton temperature word (signed 8.8 C), rounded to 0.5 C. */
#define SENSOR_THR_RAW_TO_C10(raw)                                      \
    ((int32_t)(((int32_t)(int16_t)(raw) < 0)                            \
                   ? -((int32_t)(((-(int32_t)(int16_t)(raw)) + 64) /   \
                                  128) *                                \
                       5)                                               \
                   : ((int32_t)(((int32_t)(int16_t)(raw) + 64) / 128) * \
                      5)))

/* NCT6686D pin 105: VIN0 / THR0 / V_COMP0. */
#define SIO_ADC0_ENABLED       1U
#define SIO_ADC0_TYPE          SENSOR_TYPE_VIN
#define SIO_ADC0_INDEX         0x20U
#define SIO_ADC0               "SYSTEM 12V"
#define SIO_ADC0_CALCULATE(raw) \
    ((int32_t)((((uint32_t)(raw) * 12264U) + 31U) / 63U))

/* NCT6686D pin 114: VIN1 / THR1 / V_COMP1. */
#define SIO_ADC1_ENABLED       1U
#define SIO_ADC1_TYPE          SENSOR_TYPE_VIN
#define SIO_ADC1_INDEX         0x22U
#define SIO_ADC1               "SYSTEM 5V"
#define SIO_ADC1_CALCULATE(raw) \
    ((int32_t)((uint32_t)(raw) * 80U))

/* NCT6686D pin 115: VIN2 / THR2 / V_COMP2. Currently unused. */
#define SIO_ADC2_ENABLED       0U
#define SIO_ADC2_TYPE          SENSOR_TYPE_VIN
#define SIO_ADC2_INDEX         0x24U
#define SIO_ADC2               "ADC2"
#define SIO_ADC2_CALCULATE(raw) \
    ((int32_t)((uint32_t)(raw) * 16U))

/* NCT6686D pin 116: VIN3 / THR3 / V_COMP3 / ATX5VSB. Unused. */
#define SIO_ADC3_ENABLED       0U
#define SIO_ADC3_TYPE          SENSOR_TYPE_VIN
#define SIO_ADC3_INDEX         0x26U
#define SIO_ADC3               "ADC3"
#define SIO_ADC3_CALCULATE(raw) \
    ((int32_t)((uint32_t)(raw) * 16U))

/* NCT6686D pin 109: VIN5 / THR5. */
#define SIO_ADC5_ENABLED       1U
#define SIO_ADC5_TYPE          SENSOR_TYPE_VIN
#define SIO_ADC5_INDEX         0x28U
#define SIO_ADC5               "VDIMM"
#define SIO_ADC5_CALCULATE(raw) \
    ((int32_t)((((uint32_t)(raw) * 1204U) + 18U) / 37U))

/* NCT6686D pin 106: VIN6 / THR6. */
#define SIO_ADC6_ENABLED       1U
#define SIO_ADC6_TYPE          SENSOR_TYPE_VIN
#define SIO_ADC6_INDEX         0x2AU
#define SIO_ADC6               "VCORE SENSE"
#define SIO_ADC6_CALCULATE(raw) \
    ((int32_t)((uint32_t)(raw) * 16U))

/* NCT6686D pin 107: VIN7 / THR7. */
#define SIO_ADC7_ENABLED       1U
#define SIO_ADC7_TYPE          SENSOR_TYPE_VIN
#define SIO_ADC7_INDEX         0x2CU
#define SIO_ADC7               "VCORE VRM"
#define SIO_ADC7_CALCULATE(raw) \
    ((int32_t)((uint32_t)(raw) * 16U))

/* NCT6686D pin 113: VIN14 / THR14 / TD0P. */
#define SIO_ADC14_ENABLED       1U
#define SIO_ADC14_TYPE          SENSOR_TYPE_THR
#define SIO_ADC14_INDEX         0x02U
#define SIO_ADC14               "CPU SOCKET"
#define SIO_ADC14_CALCULATE(raw) SENSOR_THR_RAW_TO_C10(raw)

/* NCT6686D pin 112: VIN15 / THR15 / TD1P. */
#define SIO_ADC15_ENABLED       1U
#define SIO_ADC15_TYPE          SENSOR_TYPE_THR
#define SIO_ADC15_INDEX         0x04U
#define SIO_ADC15               "SYSTEM TEMP"
#define SIO_ADC15_CALCULATE(raw) SENSOR_THR_RAW_TO_C10(raw)
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

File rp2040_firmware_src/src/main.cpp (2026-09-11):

/*
 * This file is part of the "ReDashboard_V2" distribution.
 *
 * Copyright (C) 2026 @himko9 <me@himko.dev>
 * Github: https://github.com/himko9/ReDashboard_V2
 *
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
 * You should have received a copy of the GNU General Public License
 * along with this program.  If not, see <https://www.gnu.org/licenses/>.
 */

#include <stdint.h>
#include <stdio.h>
#include <string.h>

#include "hardware/uart.h"
#include "pico/stdlib.h"

#include "app_config.h"
#include "board_config.h"
#include "board_io.h"
#include "buttons.h"
#include "code_history.h"
#include "display_config.h"
#include "i2c_bus.h"
#include "oled_display.h"
#include "post_uart.h"
#include "sensors.h"
#include "sio_monitor.h"

#ifndef POST80_DEBUG
#define POST80_DEBUG 0
#endif

#if POST80_DEBUG
#define DEBUG_PRINTF(...)     \
    do {                      \
        printf(__VA_ARGS__);  \
        fflush(stdout);       \
    } while (0)
#else
#define DEBUG_PRINTF(...) \
    do {                  \
    } while (0)
#endif

enum class UiMode : uint8_t {
    Normal,
    Menu,
};

static constexpr uint32_t UART_BAUD_OPTIONS[] = {
    9600U, 19200U, 38400U, 57600U,
    115200U, 230400U, 460800U, 921600U,
};
static constexpr size_t UART_BAUD_OPTIONS_COUNT =
    sizeof(UART_BAUD_OPTIONS) / sizeof(UART_BAUD_OPTIONS[0]);

static size_t find_baud_index(uint32_t baud) {
    for (size_t index = 0U; index < UART_BAUD_OPTIONS_COUNT; ++index) {
        if (UART_BAUD_OPTIONS[index] == baud) return index;
    }
    return 0U;
}

static bool sensor_change_exceeds_wake_threshold(int32_t previous,
                                                  int32_t current) {
#if SENSOR_WAKE_CHANGE_PERCENT == 0U
    (void)previous;
    (void)current;
    return false;
#else
    int64_t delta = (int64_t)current - (int64_t)previous;
    int64_t baseline = previous;
    if (delta < 0) delta = -delta;
    if (baseline < 0) baseline = -baseline;
    if (baseline == 0) return delta != 0;
    return delta * 100 >
           baseline * (int64_t)SENSOR_WAKE_CHANGE_PERCENT;
#endif
}

int main() {
    stdio_init_all();  // USB CDC serial output (ASCII)

    uint32_t uart_baud_current = UART_IN_BAUD;
    i2c_bus_init(POST_BUS);
    i2c_bus_init(OLED_BUS);
    uart_init(UART_IN_INST, uart_baud_current);
    gpio_set_function(UART_IN_RX_PIN, GPIO_FUNC_UART);
    gpio_pull_up(UART_IN_RX_PIN);
    uart_set_hw_flow(UART_IN_INST, false, false);
    uart_set_format(UART_IN_INST, 8, 1, UART_PARITY_NONE);
    uart_set_fifo_enabled(UART_IN_INST, true);
    bool uart_dma_ok = uart_dma_init();
    bool fast_uart_ok = fast_uart_init();

    board_outputs_init();
    bool mosfet_pwr_on = false;
    bool mosfet_rst_on = false;
    bool mosfet_clr_on = false;
    board_output_write(MOSFET_PWR_PIN, mosfet_pwr_on);
    board_output_write(MOSFET_RST_PIN, mosfet_rst_on);
    board_output_write(MOSFET_CLR_PIN, mosfet_clr_on);

    sleep_ms(DISPLAY_POWER_UP_DELAY_MS);

    printf("POST80 poller start\r\n");
    printf("POST bus: %s SDA=%u SCL=%u BAUD=%u TARGET=0x%02X\r\n",
           i2c_bus_name(POST_BUS.inst),
           POST_BUS.sda_pin,
           POST_BUS.scl_pin,
           POST_BUS.baud_hz,
           SIO_I2C_ADDRESS);
    printf("OLED bus: %s SDA=%u SCL=%u BAUD=%u OLED=0x%02X\r\n",
           i2c_bus_name(OLED_BUS.inst),
           OLED_BUS.sda_pin,
           OLED_BUS.scl_pin,
           OLED_BUS.baud_hz,
           OLED_I2C_ADDRESS);
    printf("Shared code buffer cap=%u\r\n", (unsigned)CODE_BUFFER_CAPACITY);
    printf("Buttons: PWR=GPIO%u RST=GPIO%u (%s)\r\n",
           BTN_PREV_PIN,
           BTN_NEXT_PIN,
           button_mode_name());
    printf("Button role: history/page scroll (five clicks change page)\r\n");
    printf("Combo hold: >%ums mode toggle, >%ums lock, >%ums CLR toggle\r\n",
           BTN_COMBO_NAV_MS, BTN_COMBO_LOCK_MS, BTN_COMBO_CLEAR_MS);
    printf("UART input: %s RX=GPIO%u BAUD=%u DMA=%s\r\n",
           uart_instance_name(UART_IN_INST), UART_IN_RX_PIN, uart_baud_current,
           uart_dma_ok ? "OK" : "OFFLINE");
    printf("Fast POST input: PIO RX=GPIO%u BAUD=%u %s\r\n",
           RP2040_FAST_UART_RX_PIN,
           RP2040_FAST_UART_BAUD,
           fast_uart_ok ? "OK" : "OFFLINE");
    printf("MOSFET outputs: PWR=GPIO%u RST=GPIO%u CLR=GPIO%u (%s)\r\n",
           MOSFET_PWR_PIN,
           MOSFET_RST_PIN,
           MOSFET_CLR_PIN,
           MOSFET_ACTIVE_LOW ? "active-low gate" : "active-high gate");
    fflush(stdout);
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

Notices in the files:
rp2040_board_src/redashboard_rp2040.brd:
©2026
